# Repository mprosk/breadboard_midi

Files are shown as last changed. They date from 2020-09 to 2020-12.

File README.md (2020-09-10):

# MIDI Breadboard Adapter
MIDI breakout board for prototyping on a breadboard. Easily communicate with digital instruments from an Arduino or other microcontroller. Includes all hardware required to drive the MIDI current loop from a UART.

## Voltage Compatibility

The breakout board can be configured to work with both 3.3V and 5V microcontrollers. Since MIDI uses current, not voltage to encode bits, the values of the current limiting resistors can be changed to reflect the different voltage level. The list of resistor values for each voltage mode is shown below.

| Resistor | 5V Bus | 3.3V Bus |
| --- | --- | --- |
| R1 | 280 | 180 |
| R2 | 220 | 220 |
| R3 | 220 | 10 |
| R4 | 220 | 33 |

## MIDI Pass Through

The adapter can also be configured to pass the MIDI IN data that it receives directly to the MIDI OUT stream, allowing your microcontroller to passively monitor the MIDI link between two other MIDI devices. Useful for debugging or for splitting the upstream data to both your project and another MIDI endpoint.

To enable this option, simply connect a jumper between the IN and OUT pins on the breadboard adapter.

## Bill of Materials

| Quantity | Line Item |
| --- | --- |
| 1 | 6N138 optoisolator |
| 1 | 8DIP socket |
| 1 | 1N914 signal diode |
| 2 | 5-pin 180' DIN socket |
| 3 | 0.1uF capacitors |
| 1 | 74LVCG125 buffer gate |
| 16 | 0.1" pitch male pin headers (4x 2-unit, 2x 4-unit) |

#### 5V Configuration

| Quantity | Line Item |
| --- | --- |
| 3 | 220 ohm resistors |
| 1 | 280 ohm resistor  |

#### 3.3V Configuration

| Quantity | Line Item |
| --- | --- |
| 1 | 10 ohm resistor  |
| 1 | 33 ohm resistor  |
| 1 | 220 ohm resistor |
| 1 | 280 ohm resistor |

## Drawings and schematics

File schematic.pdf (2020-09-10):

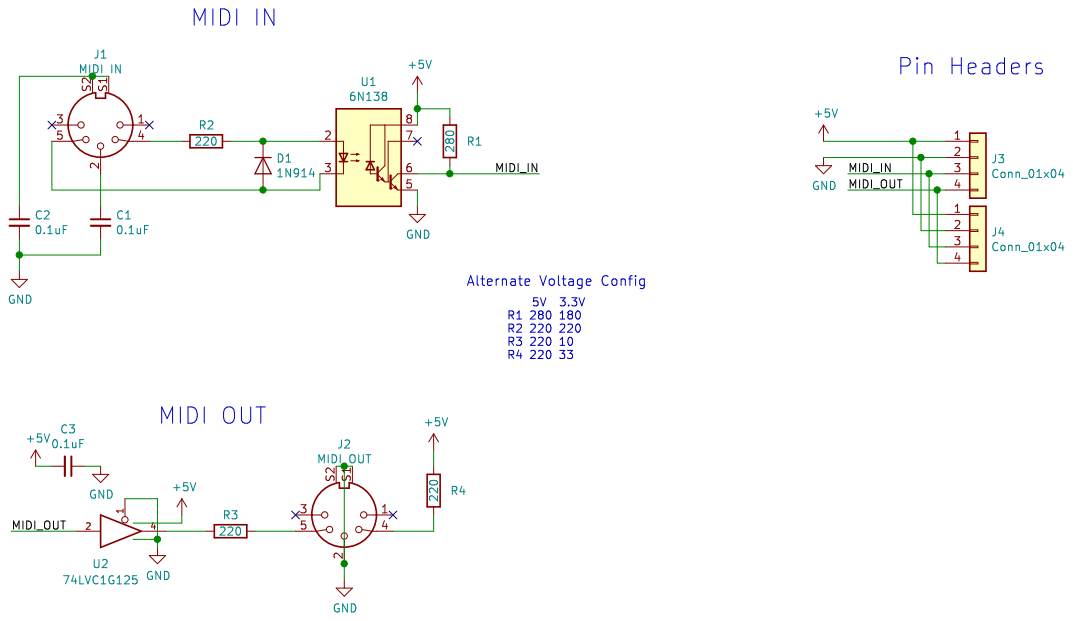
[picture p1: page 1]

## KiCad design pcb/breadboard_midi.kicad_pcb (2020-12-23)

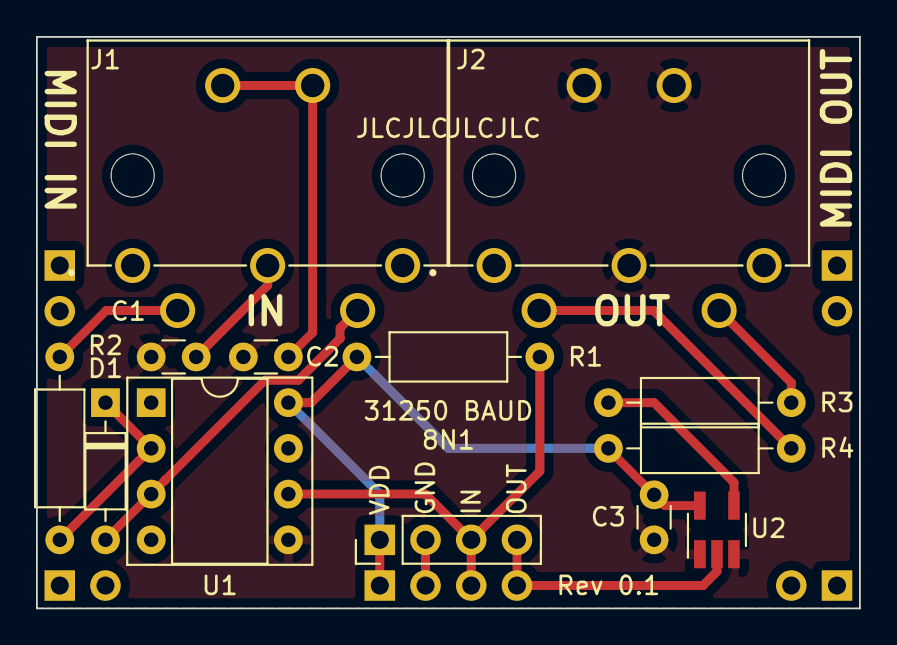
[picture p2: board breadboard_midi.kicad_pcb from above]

Board: 2 copper layers, 45.7 x 31.8 mm, 14 parts (1 on the bottom side), 12 nets.

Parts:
C1, C2, C3: 0.1uF; C_Disc_D3.0mm_W1.6mm_P2.50mm
D1: 1N914; D_DO-35_SOD27_P7.62mm_Horizontal
J1: MIDI IN; CUI_SDS-50J
J2: MIDI OUT; CUI_SDS-50J
J3, J4: Conn_01x04; PinHeader_1x04_P2.54mm_Vertical
R1: 280; R_Axial_DIN0207_L6.3mm_D2.5mm_P10.16mm_Horizontal
R2, R3, R4: 220; R_Axial_DIN0207_L6.3mm_D2.5mm_P10.16mm_Horizontal
U1: 6N138; DIP-8_W7.62mm_Socket
U2: 74LVC1G125; SOT-23-5_HandSoldering

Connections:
+5V: C3.2, J3.1, J4.1, R1.1, R4.1, U1.8, U2.5
/MIDI_IN: J3.3, J4.3, R1.2, U1.6
/MIDI_OUT: J3.4, J4.4, U2.2
GND: C1.2, C2.2, C3.1, J2.2, J2.S1, J2.S2, J3.2, J4.2, U1.5, U2.1, U2.3
unnamed: C1.1, J1.2
unnamed: C2.1, J1.S1, J1.S2
unnamed: D1.1, R2.1, U1.2
unnamed: D1.2, J1.5, U1.3
unnamed: J1.4, R2.2
unnamed: J2.4, R4.2
unnamed: J2.5, R3.1
unnamed: R3.2, U2.4

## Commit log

2020-09-09 Add KiCAD files
    [breadboard_midi-B_Cu.gbr, breadboard_midi-B_Mask.gbr, breadboard_midi-B_Paste.gbr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]
2020-09-10 Tweak schematic more
    [breadboard_midi.sch]
2020-09-10 Refresh file exports
    [breadboard_midi-B.Cu.gbr, breadboard_midi-B.Mask.gbr, breadboard_midi-B.Paste.gbr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]
2020-09-10 Move PCB files to separate folder
    [breadboard_midi.kicad_pcb, breadboard_midi.sch]
2020-09-10 Update gerber zip
2020-12-23 Refresh Gerber files
    [breadboard_midi-B.Cu.gbr, breadboard_midi-B.Mask.gbr, breadboard_midi-B.Paste.gbr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]
